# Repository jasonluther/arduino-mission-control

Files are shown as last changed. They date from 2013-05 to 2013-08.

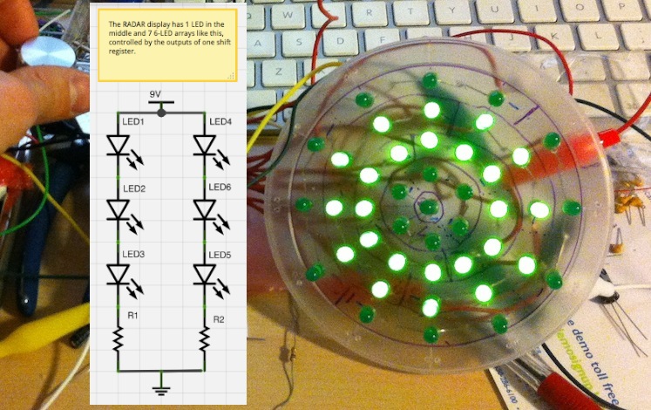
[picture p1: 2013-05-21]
docs/radar.jpg

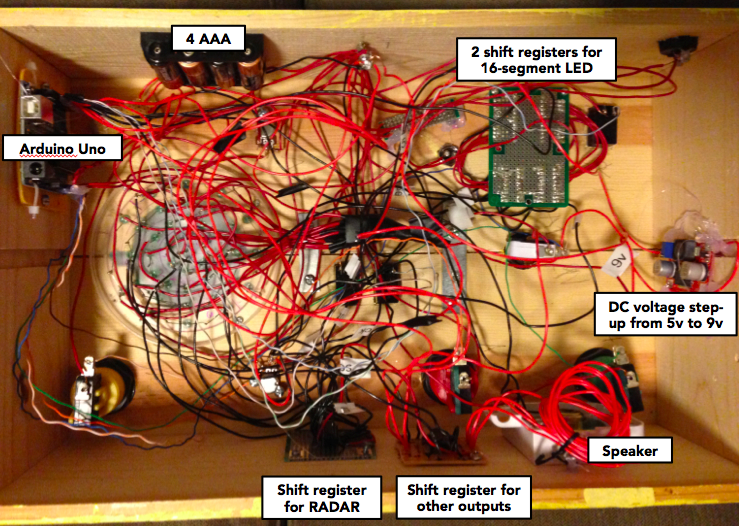
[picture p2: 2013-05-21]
docs/inside.png

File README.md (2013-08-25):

# Mission Control 1.0

This is an [Arduino](http://www.arduino.cc)-driven toy for my kids to pretend to launch a space ship or control air traffic. 

Currently, it's being used to replace a switch in a Snap Circuits kit.

See it in action at http://www.youtube.com/watch?v=Kblno1MsgNM. 

Enjoy!
Jason Luther  
<jason@ixid.net>

### Usage

THE SOFTWARE IS PROVIDED "AS IS", WITHOUT WARRANTY OF ANY KIND, EXPRESS OR IMPLIED, INCLUDING BUT NOT LIMITED TO THE WARRANTIES OF MERCHANTABILITY, FITNESS FOR A PARTICULAR PURPOSE AND NONINFRINGEMENT. IN NO EVENT SHALL THE AUTHORS BE LIABLE FOR ANY CLAIM, DAMAGES OR OTHER LIABILITY, WHETHER IN AN ACTION OF CONTRACT, TORT OR OTHERWISE, ARISING FROM, OUT OF OR IN CONNECTION WITH THE SOFTWARE OR THE USE OR OTHER DEALINGS IN THE SOFTWARE.

The software itself is placed into the public domain.

My photographs of the project are licensed under a Creative Commons Attribution-NonCommercial-ShareAlike 3.0 Unported License. See http://creativecommons.org/licenses/by-nc-sa/3.0/deed.en_US

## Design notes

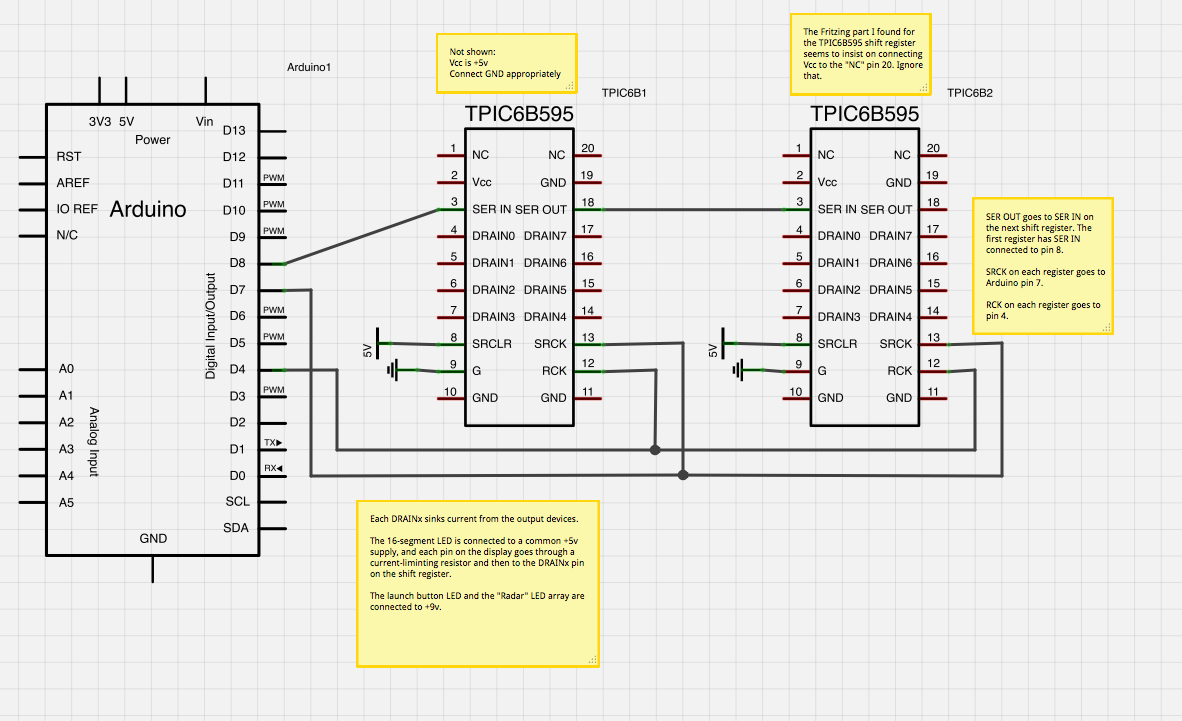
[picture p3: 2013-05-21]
docs/MissionControl-ShiftRegisters.png

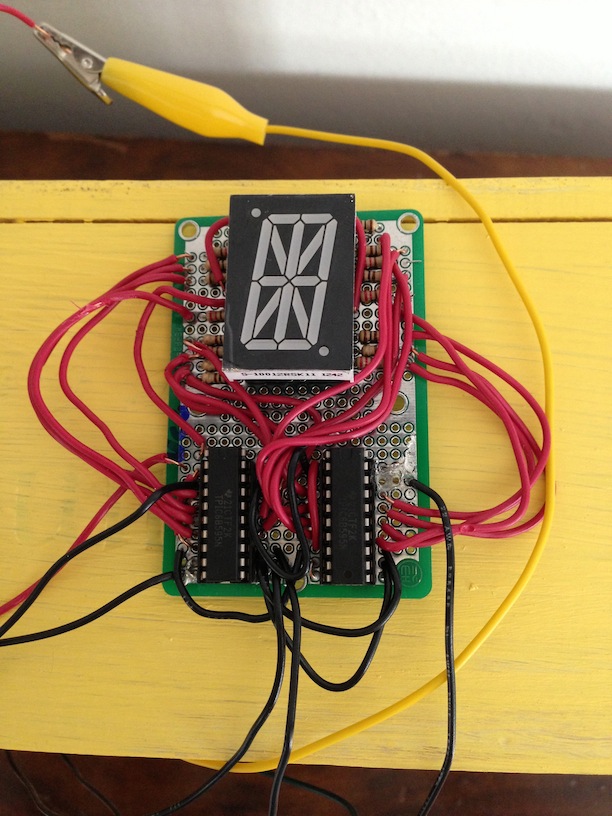
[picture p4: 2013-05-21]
docs/shift registers and 16-segment display.jpg

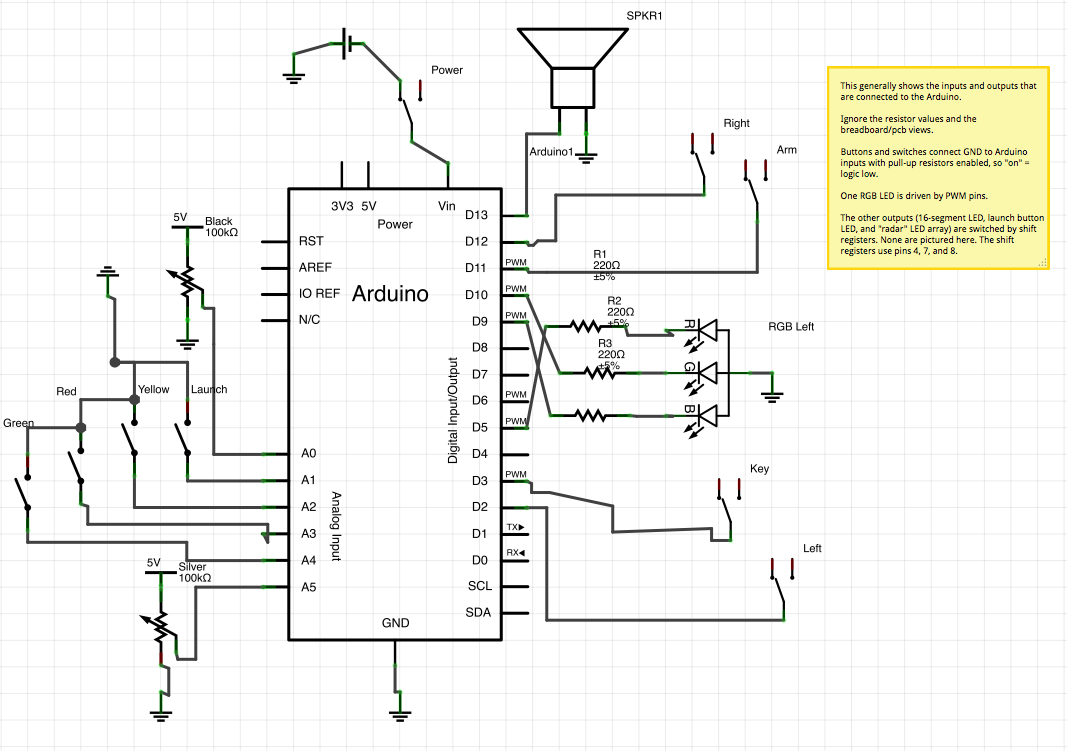
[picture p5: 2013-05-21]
docs/MissionControl-Arduino-IO.png

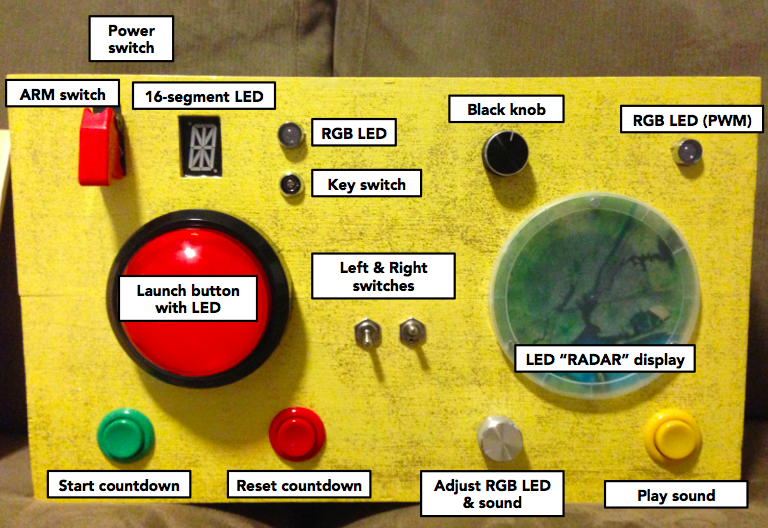
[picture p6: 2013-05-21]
docs/front.png

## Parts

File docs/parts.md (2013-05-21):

## Parts

* Any Arduino will do. I used the [Arduino Uno](https://www.sparkfun.com/products/11021). 
* The enclosure is a [wine box](http://www.plumpjackwines.com/)
* Assorted resistors
* The RADAR display cover is a yogurt lid
* [Misc.](http://www.radioshack.com/product/index.jsp?productId=2103799) [proto](https://www.sparkfun.com/products/8815) [boards](http://www.radioshack.com/product/index.jsp?productId=2104052&locale=en_US)
* Salvaged speaker

### Sparkfun

* Arcade-style buttons: [Red](https://www.sparkfun.com/products/9336), [Green](https://www.sparkfun.com/products/9341), [Yellow](https://www.sparkfun.com/products/9338)
* [Key switch](https://www.sparkfun.com/products/11473) &mdash; I have already lost the keys)
* [Missile switch cover](https://www.sparkfun.com/products/9278) &mdash; Doesn't stay open very well
* [Toggle switches](https://www.sparkfun.com/products/9276)
* [Rotary pots](https://www.sparkfun.com/products/9939) and [knob](https://www.sparkfun.com/products/10001) & [knob](https://www.sparkfun.com/products/10002)
* 4 x [TPIC6B595 shift registers](https://www.sparkfun.com/products/734) to drive the 16-segment display and other outputs
* [16-segment LED display](https://www.sparkfun.com/products/9934)
* [Launch button](https://www.sparkfun.com/products/9181)
* [RGB LED](https://www.sparkfun.com/products/11120) &mdash; common-cathode, using a 100 ohm resistor for green, 100 for blue and 220 for red with the 5v PWM output
* A whole bunch of plain old [green LEDs](https://www.sparkfun.com/products/9855) for the RADAR display
* [10mm LED holders](https://www.sparkfun.com/products/11148)
* [DIP sockets](https://www.sparkfun.com/products/7940) because I'm too chicken to solder the shift registers and 16-segment display (I cut [this](https://www.sparkfun.com/products/9095) up).
* [Power switch](https://www.sparkfun.com/products/11138)
* [Battery holder](https://www.sparkfun.com/products/552)

### Adafruit

* [Common-anode RGB LED](https://www.adafruit.com/products/848) &mdash; this LED is controlled by 3 of the shift register outputs, giving you red, green, blue, cyan, magenta, yellow, and "white." It's a very bright LED, so I connected the anode to a PWM output on the Arduino, which lets me use a lower duty cycle to dim it. 

### Amazon

* [DC setup-up converter](http://www.amazon.com/gp/product/B00AMZEUYU/ref=oh_details_o05_s03_i02?ie=UTF8&psc=1) &mdash; I designed the RADAR display to run from a 9v source, which was probably a mistake (though it saved on resistors and soldering), so I need to go from the regulated 5v supply from the Arduino (or the 6v from the batteries) to 9v. This also drives the launch button LED, which I think is meant for 12v. 
* Random 5v relay. This was a last-minute addition. I recommend buying a relay with a datasheet so you don't waste your time trying to figure out what each pin does.

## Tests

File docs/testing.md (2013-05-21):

### Unit testing Arduino code with Google Test

I'm using [Google Test](https://code.google.com/p/googletest/) for unit testing, which is a really easy way to test that the logic I have for managing state and working with inputs and outputs is correct. 

Here are some things to keep in mind when using this with Arduino:

##### Editing files

My C++ source files are all named with a `.cc` extension. That worked great while testing, but it was a pain when it came time to use the files in the Arduino IDE. 

The Arduino IDE expects C++ files to have a `.cpp` extension. Once I was ready to integrate a tested module into the IDE, I made a symlink to the `.cc` and `.h` files from their current directory into my Arduion project directory, making the `.cc` file link to a `.cpp` file. 

This scheme works fine because I was editing the `.cc` files with vim, not the Arduino IDE. Unfortunately, if you edit the symlinked files in the IDE, it overwrites them with a new copy of the file (removing your link). You also have to restart the IDE when you make changes to those files. 

A less lazy person might just [forego the IDE](http://playground.arduino.cc/Learning/CommandLine). 

##### Mock Arduino.h

Because I am not doing anything particularly complicated with the Arduino's I/O pins, it was straightforward to create a mock interface to the basic functions in `Arduino.h`. 

My mock `Arduino.c` implementation allows me to set the result of `analogRead()` or `digitalRead()` in the unit test:

    ...
    set_pin_for_test(A1, LOW);
    m.update();
    EXPECT_EQ(STATE_LAUNCHING, launchState.get_current_state()) << "Launch button";
    ...

##### Putting it together

I've tried to keep the actual `.ino` file simple so that it doesn't need its own tests and is mostly made up of calls to the unit-tested code.

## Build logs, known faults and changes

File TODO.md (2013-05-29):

# To-Do List

* Linear speed control for RADAR display.

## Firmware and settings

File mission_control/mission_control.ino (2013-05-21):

#include "InputManager.h"
#include "AnalogInput.h"
#include "DigitalInput.h"
#include "TimerInput.h"
#include "OutputPin.h"
#include "ShiftRegister.h"
#include "LaunchState.h"
#include "MusicState.h"
#include "State.h"
#include "MCState_t.h"
#include "MCEvent_t.h"
#include "Animation.h"
#include "pitches.h"
#include "Song.h"
#include "RadarRGB.h"
//#include "MemoryFree.h" // http://playground.arduino.cc/Code/AvailableMemory

/* State */
LaunchState launchState;
MusicState musicState;
int MUSIC_WAS_ON = 0;

/* Inputs */
InputManager im;
AnalogInput inputBlackKnob(A0, "Black Knob");
AnalogInput inputSilverKnob(A5, "Silver Knob");
DigitalInput inputLaunchButton(A1, "Launch Button");
DigitalInput inputYellowButton(A2, "Yellow Button");
DigitalInput inputRedButton(A3, "Red Button");
DigitalInput inputGreenButton(A4, "Green Button");
DigitalInput inputKeySwitch(3, "Key Switch");
DigitalInput inputArmSwitch(11, "Arm Switch");
DigitalInput inputRightSwitch(12, "Right Switch");
DigitalInput inputLeftSwitch(2, "Left Switch");
TimerInput inputTimer("Timer");

/* Speaker using tone() */
OutputPin pinSpeaker(13);
/* RGB LED using PWM pins */
OutputPin pinRgbRed(5);
OutputPin pinRgbGreen(10);
OutputPin pinRgbBlue(9);
/* 4 x TPIC6B595 shift registers */
OutputPin pinShiftSerial(8);
OutputPin pinShiftRCLK(4);
OutputPin pinShiftSRCLK(7);
/* RGB LED using shift register */
OutputPin pinOtherRGBShift(6);

ShiftRegister reg(&pinShiftSerial, &pinShiftSRCLK, &pinShiftRCLK);

const int launch_song_notes = 14;
const int launch_song[launch_song_notes] = { 300, 320, 100, 123, 100, 131, 100, 139, 100, 147, 100, 175, 100, 208 };
const int launch_song_duration[launch_song_notes] = { 100, 100, 400, 425, 450, 400, 300, 250, 220, 200, 180, 150, 100, 80 };
Song songLaunch(launch_song_notes, launch_song, launch_song_duration);
Song *currentSong = &songLaunch;

const int arm_notes = 3;
const int arm_song[arm_notes] = { 200, 250, 400 };
const int disarm_song[arm_notes] = { 400, 350, 200 };
const int arm_duration[arm_notes] = { 100, 100, 125 };
Song songArm(arm_notes, arm_song, arm_duration);
Song songDisarm(arm_notes, disarm_song, arm_duration);

const int count_notes = 21;
const int count_song[count_notes] = { NOTE_G3, 9, NOTE_G3 + 10, 0, NOTE_G3 + 20, 0, NOTE_G3 + 30, 0, NOTE_G3 + 40, 0, NOTE_G3 + 50, 0, NOTE_G3 + 60, 0,
NOTE_G3 + 70, 0, NOTE_G3 + 80, 0, NOTE_G3 + 90, 0, NOTE_G3 + 100 };
const int count_duration[count_notes] = { 100, 900, 100, 900, 100, 900, 100, 900, 100, 900, 100, 900, 100, 900, 100, 900, 100, 900, 100, 900, 100 };
Song songCountdown(count_notes, count_song, count_duration);

// 16-segment display
const int digits_frames = 17;
const int digits_byte1[digits_frames] = 
  { 41, 176, 188, 128, 188, 180, 48, 148, 156, 1, 172, 64, 172, 64, 172, 64, 172 };
const int digits_byte2[digits_frames] = 
  { 181, 60, 61, 52, 45, 45, 28, 61, 57, 128, 53, 64, 53, 64, 53, 64, 53 };
const int digits_duration[digits_frames] = 
  { 1000, 1000, 1000, 1000, 1000, 1000, 1000, 1000, 1000, 1000, 1000, 500, 1000, 500, 1000, 500, 10000 };
Animation digitsByte1(digits_frames, digits_byte1, digits_duration);
Animation digitsByte2(digits_frames, digits_byte2, digits_duration);

// RADAR
const int radar_frames = 6;
const int radar_byte_in[radar_frames] = { 3, 12, 48, 64, 128, 0 };
const int radar_byte_out[radar_frames] = { 128, 64, 48, 12, 3, 0 };
int radar_duration[radar_frames] = { 1000, 1000, 1000, 1000, 1000, 1000 };
Animation radarByteIn(radar_frames, radar_byte_in, radar_duration);
Animation radarByteOut(radar_frames, radar_byte_out, radar_duration); // XXX Animation should have reverse method.
Animation *currentRadarAnimation = &radarByteIn;

// Launch Button LED is pin 4 on the last shift register
const int launch_led_frames = 2;
const int launch_led_on[launch_led_frames] = { 1, 1 };
const int launch_led_off[launch_led_frames] = { 0, 0 };
const int launch_led_blink[launch_led_frames] = { 1, 0 };
const int launch_led_fast[launch_led_frames] = { 20, 20 };
const int launch_led_slow[launch_led_frames] = { 400, 600 };
Animation launchLedOn(launch_led_frames, launch_led_on, launch_led_slow);
Animation launchLedOff(launch_led_frames, launch_led_off, launch_led_slow);
Animation launchLedFast(launch_led_frames, launch_led_blink, launch_led_fast);
Animation launchLedSlow(launch_led_frames, launch_led_blink, launch_led_slow);
Animation *currentLaunchLedAnimation = &launchLedOff;

const int enabled_frames = 2;
const int enabled_byte1[enabled_frames] = { 41, 14 };
const int enabled_byte2[enabled_frames] = { 181, 64 };
const int enabled_duration[enabled_frames] = { 500, 250 };
Animation enabledByte1(enabled_frames, enabled_byte1, enabled_duration);
Animation enabledByte2(enabled_frames, enabled_byte2, enabled_duration);

const int launching_frames = 4;
const int launching_byte1[launching_frames] = { 4, 16, 128, 83 };
const int launching_byte2[launching_frames] = { 1, 8, 32, 202 };
const int launching_duration[launching_frames] = { 500, 400, 300, 800 };
Animation launchingByte1(launching_frames, launching_byte1, launching_duration);
Animation launchingByte2(launching_frames, launching_byte2, launching_duration);

const int disabled_frames = 2;
const int disabled_byte1[disabled_frames] = { 0, 0 };
const int disabled_byte2[disabled_frames] = { 66, 0 };
const int disabled_duration[disabled_frames] = { 500, 250 };
Animation disabledByte1(disabled_frames, disabled_byte1, disabled_duration);
Animation disabledByte2(disabled_frames, disabled_byte2, disabled_duration);

const int at_zero_frames = 12;
const int at_zero1[at_zero_frames] = 
  { 128, 0, 0, 0, 0, 4, 8, 32, 172, 64, 172, 64, };
const int at_zero2[at_zero_frames] = 
  { 0, 32, 16, 4, 1, 0, 0, 0, 53, 64, 53, 64 };
const int at_zero_duration[at_zero_frames] = 
  { 50, 50, 50, 50, 50, 50, 50, 50, 100, 100, 100, 100 };
Animation atZeroByte1(at_zero_frames, at_zero1, at_zero_duration);
Animation atZeroByte2(at_zero_frames, at_zero2, at_zero_duration);

Animation *current16SegmentAnimationByte1 = &enabledByte1;
Animation *current16SegmentAnimationByte2 = &enabledByte2;
MCState_t previousLaunchState;

void setup() {
  Serial.begin(115200);
  Serial.println("setup()");

   /* Inputs */
  im.add_input(&inputBlackKnob);
  im.add_input(&inputSilverKnob);
  im.add_input_with_state(&inputLaunchButton, &launchState, EVENT_LAUNCH, EVENT_NOOP);
  im.add_input_with_state(&inputYellowButton, &musicState, EVENT_START_MUSIC, EVENT_STOP_MUSIC);
  im.add_input_with_state(&inputRedButton, &launchState, EVENT_RESET_COUNTDOWN, EVENT_NOOP);
  im.add_input_with_state(&inputGreenButton, &launchState, EVENT_START_COUNTDOWN, EVENT_NOOP);
  im.add_input_with_state(&inputKeySwitch, &launchState, EVENT_NOOP, EVENT_NOOP);
  im.add_input_with_state(&inputArmSwitch, &launchState, EVENT_ARM, EVENT_DISARM);
  im.add_input_with_state(&inputTimer, &launchState, EVENT_NOOP, EVENT_TIMER_EXPIRED);
  im.add_input(&inputRightSwitch);
  im.add_input(&inputLeftSwitch);
  im.setup();

  /* Outputs */
  // RGB LED
  pinRgbRed.setup();
  pinRgbRed.set_high();
  pinRgbGreen.setup();
  pinRgbGreen.set_high();
  pinRgbBlue.setup();
  pinRgbBlue.set_high();

  // Speaker
  pinSpeaker.setup();

  // Shift register
  pinShiftSerial.setup();
  pinShiftRCLK.setup();
  pinShiftSRCLK.setup();
  //reset all register pins
  for (int i = 0; i < 4; i++) {
    reg.set_byte(i, 0);
  }
  reg.shift_out();
  
  // The "other" RGB LED is too bright at full +5v duty cycle, so use PWM to dim it.
  pinOtherRGBShift.setup();
  pinOtherRGBShift.set_pwm(64);
  
  previousLaunchState = STATE_OFF;
  if (inputArmSwitch.value() == LOW) {
    launchState.handle_event(EVENT_ARM); 
  }
}

void loop() {

  /* Inputs */
  im.update();

  /* Outputs */
  MCState_t currentLaunchState = launchState.get_current_state();
  if (currentLaunchState != previousLaunchState) {
    Serial.print("Changing states from ");
    Serial.print(previousLaunchState);
    Serial.print(" to ");
    Serial.println(currentLaunchState);
    
    previousLaunchState = currentLaunchState;
    int red = 0; int green = 0; int blue = 0; 
    int relay_on = 0;

    switch(currentLaunchState) {
      case STATE_COUNTDOWN_DISABLED:
        current16SegmentAnimationByte1 = &disabledByte1;
        current16SegmentAnimationByte2 = &disabledByte2;
        currentLaunchLedAnimation = &launchLedOff;
        red = 1; green = 0; blue = 1;
        relay_on = 0;
        currentSong = &songDisarm;
        currentSong->reset();
        break;
      case STATE_COUNTDOWN_ENABLED:
        current16SegmentAnimationByte1 = &enabledByte1;
        current16SegmentAnimationByte2 = &enabledByte2;
        currentLaunchLedAnimation = &launchLedOff;
        red = 0; green = 1; blue = 1;
        relay_on = 0;
        currentSong = &songArm;
        currentSong->reset();
        break;
      case STATE_COUNTDOWN_COUNTING:
        current16SegmentAnimationByte1 = &digitsByte1;
        current16SegmentAnimationByte2 = &digitsByte2;
        red = 0; green = 0; blue = 1;
        relay_on = 0;
        currentLaunchLedAnimation = &launchLedSlow;
        pinSpeaker.set_tone(550, 1000);
        currentSong = &songCountdown;
        currentSong->reset();
        inputTimer.set_timer(10200);
        break;
      case STATE_COUNTDOWN_AT_ZERO:
        current16SegmentAnimationByte1 = &atZeroByte1;
        current16SegmentAnimationByte2 = &atZeroByte2;
        currentLaunchLedAnimation = &launchLedFast;
        red = 0; green = 1; blue = 0;
        relay_on = 0;
        pinSpeaker.set_tone(345, 1000);
        break;
      case STATE_LAUNCHING:
        current16SegmentAnimationByte1 = &launchingByte1;
        current16SegmentAnimationByte2 = &launchingByte2;
        currentLaunchLedAnimation = &launchLedOn;
        red = 1; green = 0; blue = 0;
        relay_on = 1;
        currentSong = &songLaunch;
        currentSong->reset();
        inputTimer.set_timer(10200);
        break;
      default:
        current16SegmentAnimationByte1 = &disabledByte1;
        current16SegmentAnimationByte2 = &disabledByte2;
        currentLaunchLedAnimation = &launchLedOff;
        red = 1; green = 1; blue = 1;
        relay_on = 0;
        break;      
    }
    current16SegmentAnimationByte1->reset();
    current16SegmentAnimationByte2->reset();
    currentLaunchLedAnimation->reset();
    reg.set_bit(3, 5, red);
    reg.set_bit(3, 6, green);
    reg.set_bit(3, 7, blue);
    reg.set_bit(3, 3, relay_on);
  }
  unsigned long now = millis();
  current16SegmentAnimationByte1->animate(now);
  current16SegmentAnimationByte2->animate(now);
  reg.set_byte(0, (unsigned char)current16SegmentAnimationByte1->get_content());
  reg.set_byte(1, (unsigned char)current16SegmentAnimationByte2->get_content());

  if (inputRightSwitch.value() == HIGH) {
    currentRadarAnimation = &radarByteIn;
  } else {
    currentRadarAnimation = &radarByteOut;
  }  int black_knob_value = map(inputBlackKnob.value(), 0, 1023, 50, 500);
  for (int i = 0; i < radar_frames; i++) {
    radar_duration[i] = black_knob_value; 
  }
  currentRadarAnimation->animate(now);
  reg.set_byte(2, (unsigned char)currentRadarAnimation->get_content());
  
  int hue = map(inputSilverKnob.value(), 0, 1023, 0, 359);
  set_rgb_from_hue(&pinRgbRed, &pinRgbGreen, &pinRgbBlue, hue);

  if (musicState.get_current_state() == STATE_MUSIC_ON) {
    pinSpeaker.set_tone(map(inputSilverKnob.value(), 0, 1024, 200, 2600));
    MUSIC_WAS_ON = 1;
  } else {
    if (MUSIC_WAS_ON) {
      pinSpeaker.no_tone();
      MUSIC_WAS_ON = 0;
    }
    currentSong->play(&pinSpeaker, millis());
  }

  // Launch Button LED
  currentLaunchLedAnimation->animate(now);
  reg.set_bit(3, 4, (unsigned char)currentLaunchLedAnimation->get_content());

  reg.shift_out();
    
  delay(20);

}

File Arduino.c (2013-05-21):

#include "Arduino.h"
#include <iostream>

int PINMODE[20];
int PINVALUE[20];
unsigned long _millis = 0;

int get_pinmode_for_test(int pin) {
  std::cout << "get_pinmode_for_test(" << pin << ") = " << PINMODE[pin] << ")\n";
  return PINMODE[pin];
}

void set_pin_for_test(int pin, int value) {
  std::cout << "set_pin_for_test(" << pin << ", " << value << ")\n";
  PINVALUE[pin] = value;
}

void pinMode(int pin, int mode) {
  std::cout << "pinMode(" << pin << ", " << mode << ")\n";
  PINMODE[pin] = mode;
  PINVALUE[pin] = 0;
}

int digitalRead(int pin) {
  std::cout << "digitalRead(" << pin << ") = " << PINVALUE[pin] << "\n";
  return PINVALUE[pin];
}

int analogRead(int pin) {
  std::cout << "analogRead(" << pin << ") = " << PINVALUE[pin + 14] << "\n";
  return PINVALUE[pin + 14];
}

void digitalWrite(int pin, int value) {
  set_pin_for_test(pin, value);
}

void analogWrite(int pin, int value) {
  set_pin_for_test(pin + 14, value);
}

void tone(int pin, int value) {
  set_pin_for_test(pin, value);
}

void tone(int pin, int value, int duration) {
  duration = 0; /* Unused in mock test */
  set_pin_for_test(pin, value);
}

void noTone(int pin) {
  set_pin_for_test(pin, 0);
}

unsigned long millis(void) {
  return _millis;
}

void set_millis_for_test(unsigned long new_millis) {
  _millis = new_millis;
}
